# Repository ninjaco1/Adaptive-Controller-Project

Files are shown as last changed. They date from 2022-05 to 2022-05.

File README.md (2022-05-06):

# Adaptive-Controller-Project

ECE 44x Group 18
by Anthony Nguyen, Don Nguyen, Alyssa Estenson, Jordyn Marshall

The purpose of this project is to develop a controller which can act as a keyboard and a mouse when utilized with a computer. This controller is designed to help amputees or those incapable of controlling individual fingers be able to interact with a computer efficiently. This controller falls under the category of assistive technology, hoping to increase participation among the desired user group. The team has designed and prototyped an assistive controller that utilizes joysticks and large buttons to help those who lack fingers and appendages interact with a computer, when they would otherwise be unable to interact with a standard keyboard and handheld mouse.

This controller provides keyboard and mouse functionality. This controller has been designed to be intuitive for the expected disabled user group, and can be operated accurately and precisely. The device itself has been implemented to be integrable with the target user’s daily activities, meaning it is safe and is protected to allow only limited dust and particle ingress. The controller is powered and connected to the computer via a USB cable. The risks and impacts in several fields have been considered for this project in the final design and implementation of the system.

The team has designed the system by creating a block diagram and defining the interface connections between each block. The push buttons and joysticks are both blocks which allow for the user to interact with the system, while an input modification block is included so that these electronics can be properly utilized by the disabled user. All the inputs would then be processed by the Arduino, which is mounted to a PCB and connected to the rest of the system. The Arduino and any other electrical circuits would be contained within a smaller, safe enclosure within the system itself. Once the Arduino has interpreted the proper inputs, it would then tell the computer how to manipulate the cursor or what to type into a word processor based on the given inputs. This would be done with the keyboard serial and mouse serial blocks.

The team has since developed all blocks and integrated them together into a complete system. The system was shown to meet all of the project’s requirements and thus assert itself as a functional prototype. The team has since begun to close out the project, and have placed all information for future teams within the project closing section. The team has made several recommendations to improve future projects. As such, the project would be easily continued by future teams. These recommendations include implementing a testbench into the design, utilizing an I2C multiplexer for the joysticks, redesigning the enclosure for better fasteners, and include a demonstration for accuracy. The team also made global impact recommendations, which include finding a target user and lowering cost, as well as teamwork recommendations, which involve more synchronous meetings and task delegation.

## Getting things started
The system will start up and will display on the screen of what mouse sentivity the user wants. Each buttons will be a different DPI. Each Colored button will either be caps lock, shift, ctrl, or alt. To type a certain letter to the screen you move each controller in a certain different. If unsure where the letters are just hold the left joystick in a certain different for 1 second and the OLED display will show the possible letters that you want to type. If you want to use the mouse then just move only the right joystick. For a left click push down on the left joystick. For a right click push down on the right joystick.

## Images
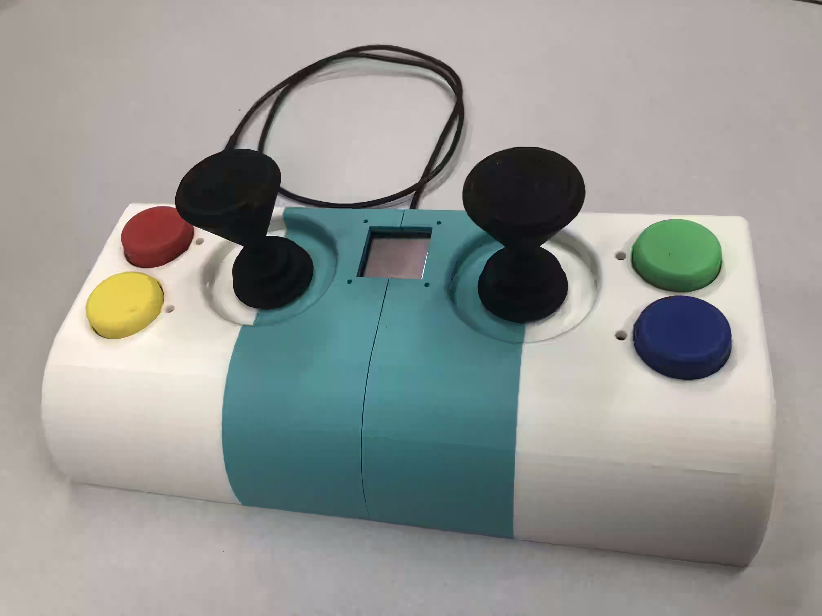
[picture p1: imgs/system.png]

<br>

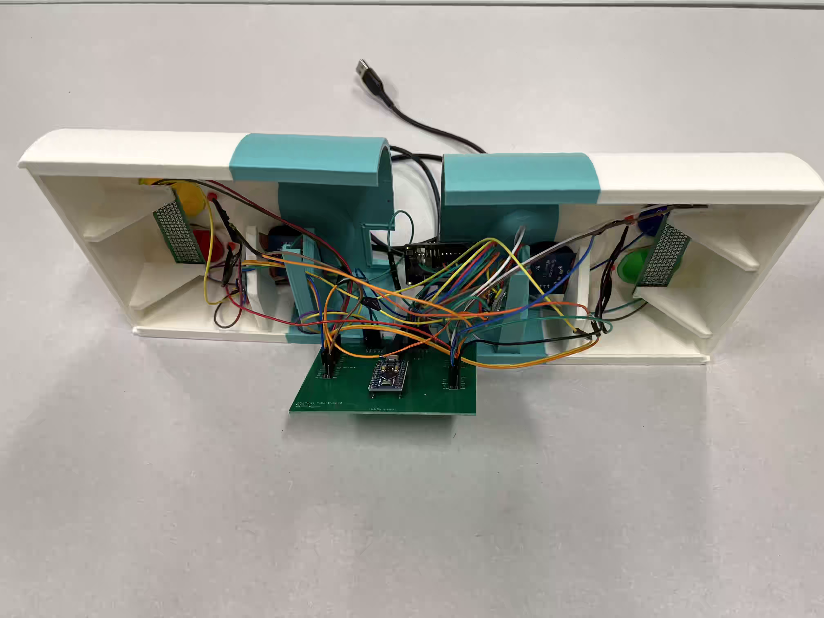
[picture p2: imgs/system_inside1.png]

<br>
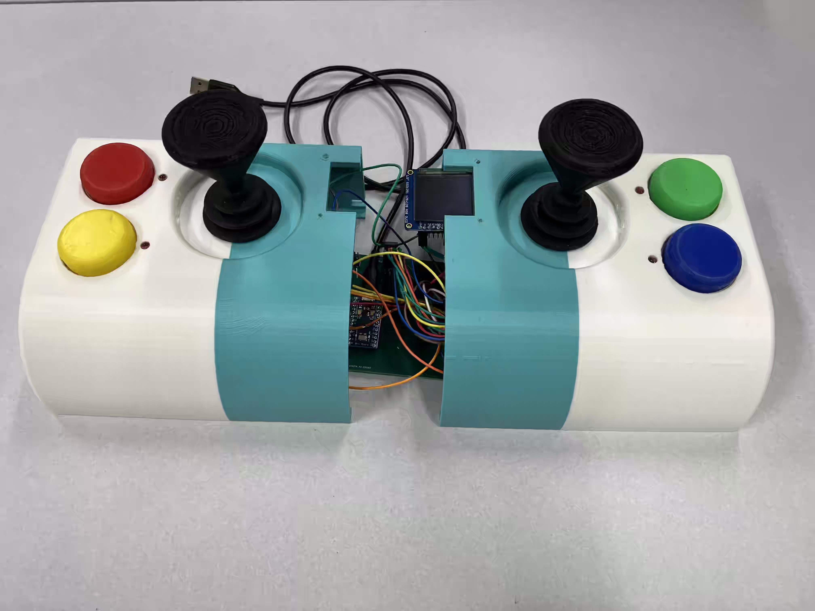
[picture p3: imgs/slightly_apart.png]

<br>

### Schematic of Connections


<br>

### Key mapping
<br>


## Links
[OSU Project Showcase](https://eecs.oregonstate.edu/project-showcase/projects/?id=dvNoBaSVptpGct7d)

[Project Poster](https://docs.google.com/presentation/d/1d2c_HKdiV-RKjupTTuDAdYsf7zG3z4g_/edit#slide=id.p1)

[BOM](https://docs.google.com/spreadsheets/d/1IXuZZz__ufx8j4xxZ3oTDNYRYh3Tj-c8Vc7RmFHtK2w/edit)

## Videos
[Keyboard Test video](https://drive.google.com/file/d/1GGf7FCQeNJFhevCrC33tzXw3Ll04iI_N/view)

[Mouse Test video](https://drive.google.com/file/d/1AdtP7RRNI2bLkL078hBE3vfOJWtM9V73/view)

[Drop Test video](https://drive.google.com/file/d/1iQLp1Ob5c2PGEaCn-phhR27NIFKvISCt/view)

[Sand Test Video](https://drive.google.com/file/d/1Eg6IK6emiSHccY-DuzBPpM0ZAq6DRVJi/view)

[Pasting Demo](https://drive.google.com/file/d/1w3BZ9_08Sq80-XbKwkToTu9jihAmKI4g/view)

[Testing Input Delay](https://drive.google.com/file/d/1sHcw7LDEvQJ_JNjOiiO1o_LZl5gAdzr4/view)

[Menu Display Testing](https://drive.google.com/file/d/1sHcw7LDEvQJ_JNjOiiO1o_LZl5gAdzr4/view)

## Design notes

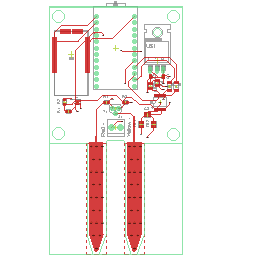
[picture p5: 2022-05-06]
F/_HC_Thesis_PCB.92a26f0b-b337-44cd-ba37-0ec76b757aee.png

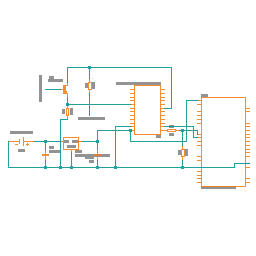
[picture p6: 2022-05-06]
F/_HC_Thesis_Schematic.0f503704-76ca-4dae-937e-57e30101aeb6.png

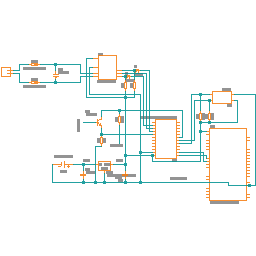
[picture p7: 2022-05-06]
F/_HC_Thesis_Schematic.15e804ea-fe3e-409c-88e3-dcfe19e1805c.png

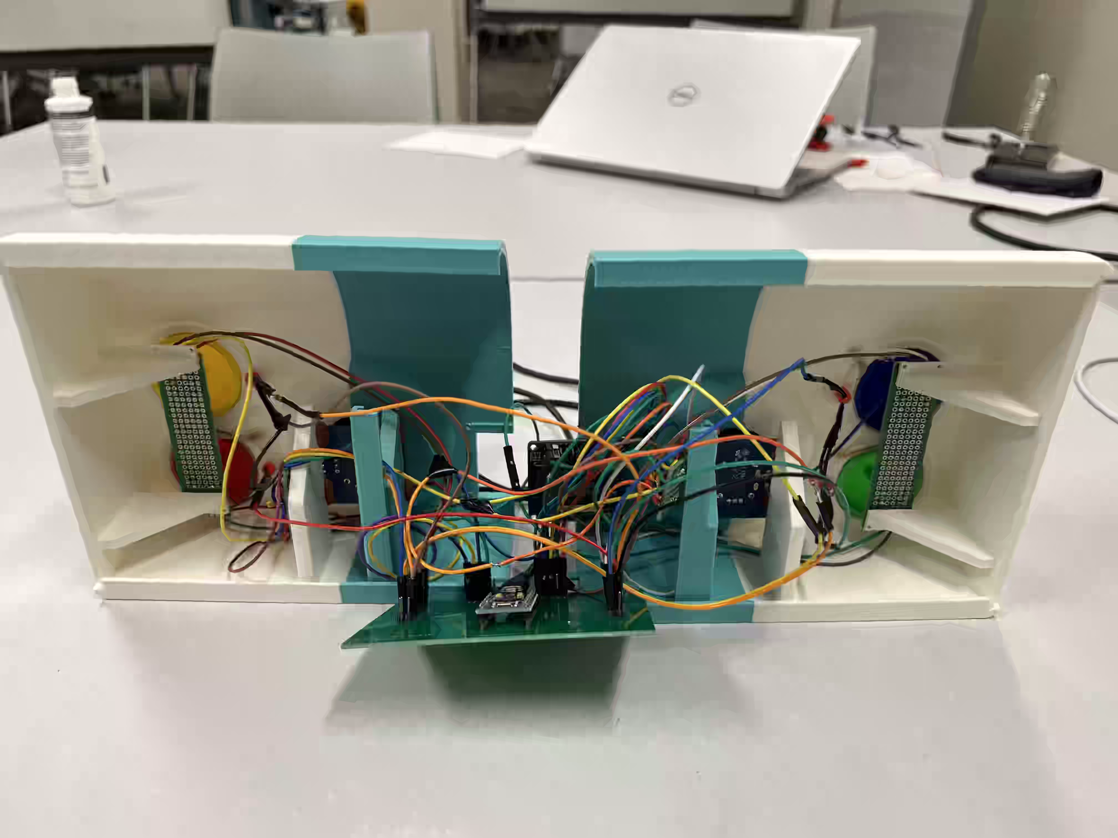
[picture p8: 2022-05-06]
imgs/system_inside2.png

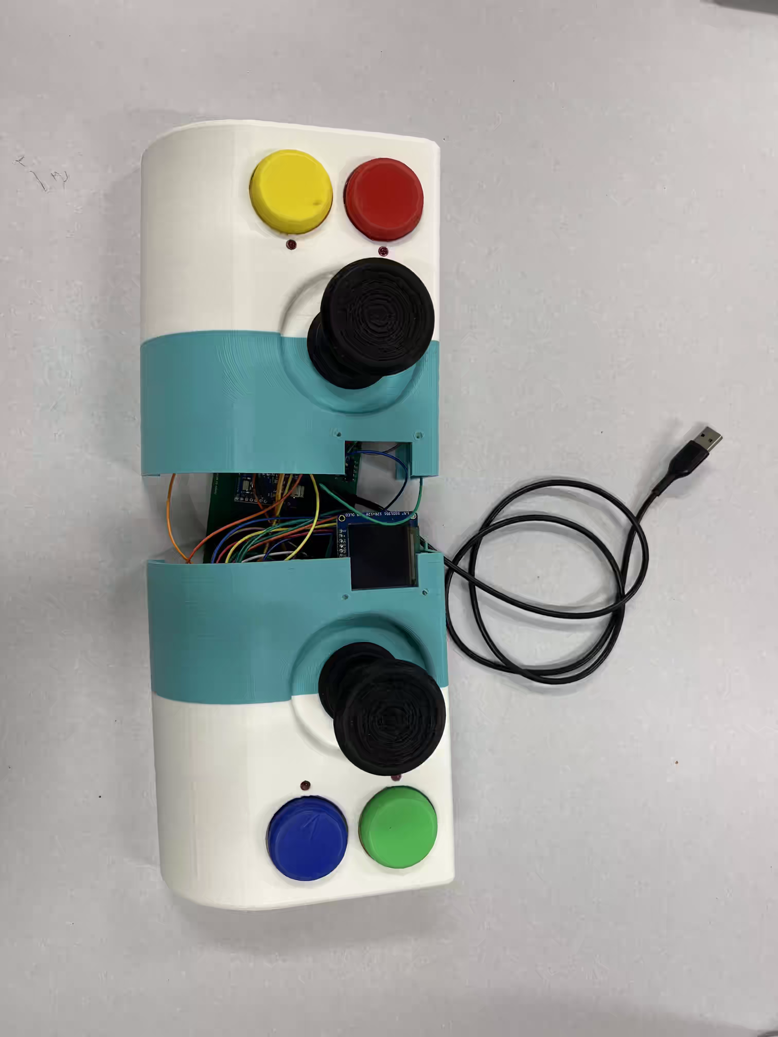
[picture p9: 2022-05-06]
imgs/vertical_slightly apart.png

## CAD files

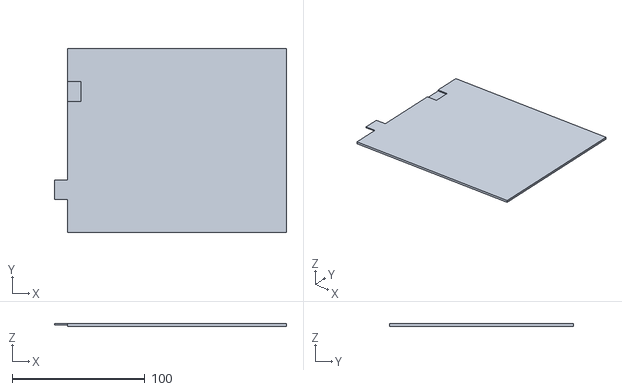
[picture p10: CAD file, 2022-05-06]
SlideLeft v1.stl
174.8 x 139.0 x 1.90

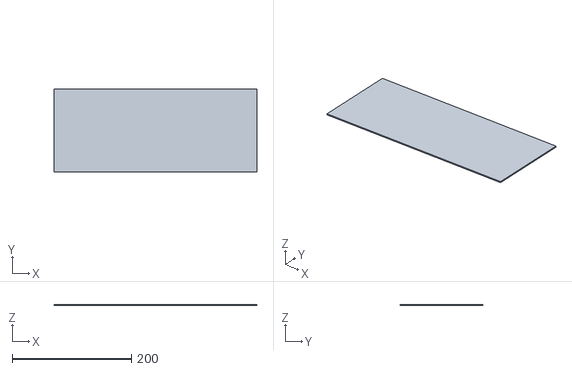
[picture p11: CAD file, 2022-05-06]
Bottom Slide v1.stl
340.0 x 139.0 x 1.90

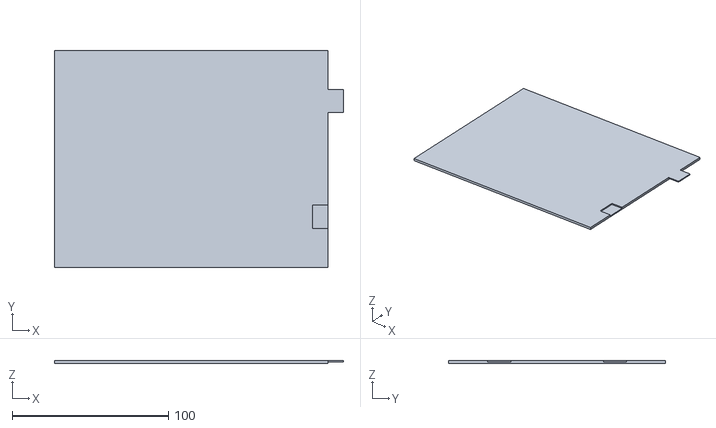
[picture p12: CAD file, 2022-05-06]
SlideRight v1.stl
184.8 x 139.0 x 1.90

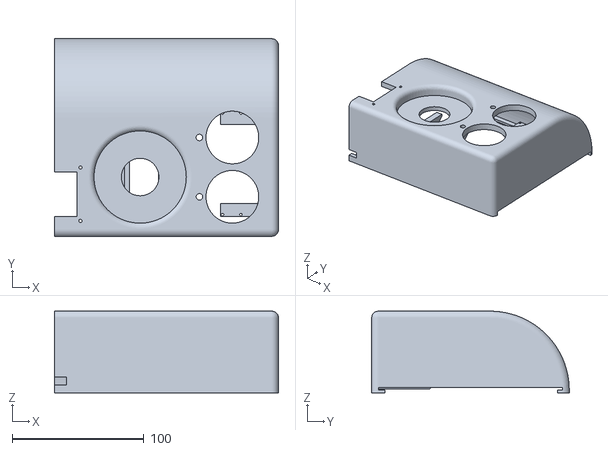
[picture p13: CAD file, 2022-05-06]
EnclosureLeft2 v1.stl
170.0 x 150.0 x 62.0

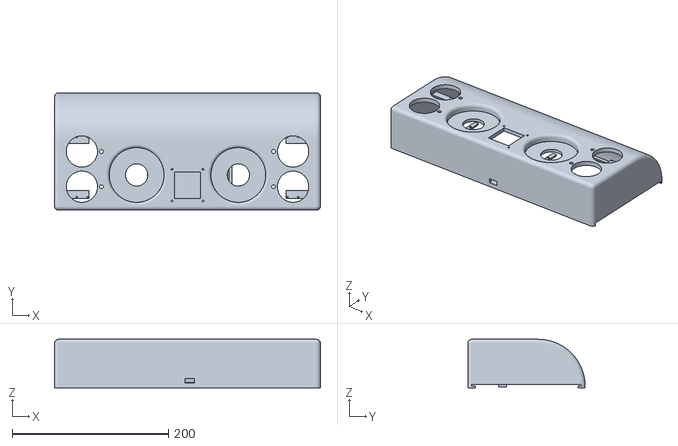
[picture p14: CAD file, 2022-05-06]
EnclosureEdit v5.stl
340.0 x 150.0 x 62.0

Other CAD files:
EnclosureRight v1.stl
EnclosureLeft2 v1.f3d
F/_Bottom Slide Drawing.b6d973e9-bf5a-411e-be44-02bcf0958e85.f2d
F/_Bottom Slide.52f3d79a-d360-466b-9179-13a9d49c522c.f3d
F/_Enclosure.4db8caeb-8215-4af4-88ae-bd1e58a5b23c.f3d
F/_EnclosureAdjust.fc7c3453-6717-43be-b58f-f00bd7b97b80.f3d
F/_EnclosureEdit Drawing.40aac79c-d90c-4c43-845f-02b9d95ee5f7.f2d
F/_EnclosureEdit.7de098fb-cdc2-4d50-8657-6a43fb820375.f3d
F/_EnclosureLeft.1aa5190f-d5e4-4d97-9be4-42d8a4ec4a47.f3d
F/_EnclosureLeft2.d6a65141-9274-40d2-aae8-db812ca37aa2.f3d
F/_EnclosureRight.7b88efe1-b6f1-4124-831b-9d16f9bb9ea6.f3d
F/_SlideLeft.8e61a6cf-9e6c-482f-872f-dd21ef670e3e.f3d
F/_SlideRight.b5ac7882-bd10-4640-b8c8-33c303472b0b.f3d

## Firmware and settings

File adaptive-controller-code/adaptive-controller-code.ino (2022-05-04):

// FEATURE SWITCH
#define MOUSEBLOCK TRUE;
#define JOYSTICKBUTTONBLOCK TRUE;
#define KEYBOARDBLOCK TRUE;
#define OLEDBLOCK TRUE;

#ifdef OLEDBLOCK
// You can use any (4 or) 5 pins
#define SCLK_PIN 15
#define MOSI_PIN 16
#define DC_PIN 8
#define CS_PIN 10
#define RST_PIN 7

// one of these 3 includes conflicts with the joysticks
#include <Adafruit_GFX.h>
#include <Adafruit_SSD1351.h>
#include <SPI.h>

// Color definitions
#define BLACK 0x0000
#define BLUE 0x001F
#define RED 0xF800
#define GREEN 0x07E0
#define CYAN 0x07FF
#define MAGENTA 0xF81F
#define YELLOW 0xFFE0
#define WHITE 0xFFFF
#define PURPLE 0x7810
#define ORANGE 0xFC00

// Screen dimensions
#define SCREEN_WIDTH 128
#define SCREEN_HEIGHT 128

Adafruit_SSD1351 tft = Adafruit_SSD1351(SCREEN_WIDTH, SCREEN_HEIGHT, CS_PIN, DC_PIN, MOSI_PIN, SCLK_PIN, RST_PIN);
bool setMouseSpeedFlag = false;
#endif

#ifdef JOYSTICKBUTTONBLOCK
#include "keyboard_serial_header.hpp"
#include <Wire.h>
#include "SparkFun_Qwiic_Joystick_Arduino_Library.h" //https://www.sparkfun.com/products/15168
//#include <TFT.h>
#define OFF 0
#define ON 1
#define RIGHT 2
#define LEFT 1
#endif

#ifdef MOUSEBLOCK
#include "Assistive_Mouse.h"
#endif

// declare joystick objects
#ifdef JOYSTICKBUTTONBLOCK
JOYSTICK Lstick;
JOYSTICK Rstick;
#endif

// declare keyboard object
#ifdef KEYBOARDBLOCK
Key k;
#endif

// declare mouse
#ifdef MOUSEBLOCK
Assistive_Mouse mouse;
#endif

#ifdef JOYSTICKBUTTONBLOCK
uint8_t Laddress = 0x20; // I2C address for left joystick (default)
uint8_t Raddress = 0x21; // I2C address for right joystick (reprogrammed)

// variables to hold joystick input
uint16_t LinX = 512; // ADC "coordinate" value from the ATtiny85
uint16_t LinY = 512; // ADC "coordinate" value from the ATtiny85
uint16_t RinX = 512; // ADC "coordinate" value from the ATtiny85
uint16_t RinY = 512; // ADC "coordinate" value from the ATtiny85
uint8_t Lkey = 00;   // input to convey to keyboard
uint8_t Rkey = 00;   // input to convey to keyboard

unsigned long timepass = 0; // variable to track time, start at 0

// button status variables, default OFF
uint8_t Lclick = OFF;
uint8_t Rclick = OFF;
uint8_t CAPS = OFF;  // CAPS state will be toggled...
uint8_t Shift = OFF; //... while other buttons work directly as switches
uint8_t Ctrl = OFF;
uint8_t Alt = OFF;
#endif

//******************************************************************************
//                            chk_buttons
// Checks the state of the button number passed to it. It shifts in ones till
// the button is pushed. Function returns a 1 only once per debounced button
// push so a debounce and toggle function can be implemented at the same time.
// Adapted to check all buttons from Ganssel's "Guide to Debouncing"
// Expects active low pushbuttons on PINA port.  Debounce time is determined by
// external loop delay times 12. Looks for rising edge on button so held actions
// have no unexpected effect.
//******************************************************************************
uint8_t chk_buttons(uint8_t pin)
{
    static uint16_t state = 0;                          // holds state of debounce reading
    state = (state << 1) | (digitalRead(pin)) | 0xE000; // mask on PINA button
    if (state == 0xEFFF)                                // compares to rising edge value (so holding doesn't stack)
        return 1;

    // if not true for 12 times, return false
    return 0;
}

//******************************************************************************
//                            chk_click
// Checks the state of the click passed to it. It shifts in ones till
// the button is pushed. Function returns a 1 only once per debounced button
// push so a debounce and toggle function can be implemented at the same time.
// Adapted to check all buttons from Ganssel's "Guide to Debouncing"
// Expects active low pushbuttons on PINA port.  Debounce time is determined by
// external loop delay times 12. Looks for rising edge on button so held actions
// have no unexpected effect.
//******************************************************************************
uint8_t chk_click(uint8_t which_click)
{
    static uint8_t state1 = 0; // holds state of right debounce reading
    static uint8_t state2 = 0; // holds state of left debounce
    if (which_click == RIGHT)
    {                                                          // right click
        state1 = (state1 << 1) | (!Rstick.getButton()) | 0xE0; // mask
        if (state1 == 0xEF)                                    // compares to rising edge value (so holding doesn't stack)
            return 1;

        // if not true for 4 times, return false
        return 0;
    }

    if (which_click == LEFT)
    {                                                          // left click
        state2 = (state2 << 1) | (!Lstick.getButton()) | 0xE0; // mask
        if (state2 == 0xEF)                                    // compares to rising edge value (so holding doesn't stack)
            return 1;

        // if not true for 4 times, return false
        return 0;
    }
}

//******************************************************************************
//                            mode_selector
//
//******************************************************************************
void mode_selector(uint8_t selector, uint8_t shift, uint8_t caps)
{
    switch (selector)
    {
    case 0:
        if(shift)
            visual_aid_display('K', 'O', ' ', 'M', ' ', ' ', 'L', 'N');
        else if(caps)
            visual_aid_display('K', 'O', ' ', 'M', ' ', ' ', 'L', 'N');
        else
            visual_aid_display('k', 'o', ' ', 'm', ' ', ' ', 'l', 'n');
        break;
    case 1:
        if(shift)
            visual_aid_display('P', 'T', '{', 'R', '}', ' ', 'Q', 'S');
        else if(caps)
            visual_aid_display('P', 'T', '[', 'R', ']', ' ', 'Q', 'S');
        else
            visual_aid_display('p', 't', '[', 'r', ']', ' ', 'q', 's');
        break;
    case 2:
        if(shift)
            visual_aid_display('U', 'Y', '\\', 'W', ' ', ' ', 'V', 'X');
        else if(caps)
            visual_aid_display('U', 'Y', '\\', 'W', ' ', ' ', 'V', 'X');
        else
            visual_aid_display('u', 'y', '\\', 'w', ' ', ' ', 'v', 'x');
        break;
    case 3:
        if(shift)
            visual_aid_display('<', 'Z', ' ', '"', ' ', ' ', '>', '?');
        else if(caps)
            visual_aid_display(',', 'Z', ' ', '\'', ' ', ' ', '.', '/');
        else
            visual_aid_display(',', 'z', ' ', '\'', ' ', ' ', '.', '/');
        break;
    case 4:
        if(!shift)
            visual_aid_display('6', '0', '-', '8', '=', ' ', '7', '9');
        else
            visual_aid_display('^', ')', '_', '*', '+', ' ', '&', '(');
        break;
    case 5:
        if(!shift)
            visual_aid_display('1', '5', ' ', '3', ' ', ' ', '2', '4');
        else
            visual_aid_display('!', '%', ' ', '#', ' ', ' ', '@', '$');
        break;
    case 6:
        if(shift)
            visual_aid_display('A', 'E', ' ', 'C', ' ', ' ', 'B', 'D');
        else if(caps)
            visual_aid_display('A', 'E', ' ', 'C', ' ', ' ', 'B', 'D');
        else
            visual_aid_display('a', 'e', ' ', 'c', ' ', ' ', 'b', 'd');
        break;
    case 7:
        if(shift)
            visual_aid_display('F', 'J', ' ', 'H', ' ', ' ', 'G', 'I');
        else if(caps)
            visual_aid_display('F', 'J', ' ', 'H', ' ', ' ', 'G', 'I');
        else
            visual_aid_display('f', 'j', ' ', 'h', ' ', ' ', 'g', 'i');
        break;
    default:
        tft.fillScreen(BLACK);
    }
}

//******************************************************************************
//                            visual_aid_display
//
//******************************************************************************
void visual_aid_display(char one, char two, char three, char four, char five, char six, char seven, char eight)
{
    //tft.fillScreen(BLACK);
    tft.fillCircle(tft.width() / 2, tft.height() / 2, tft.height() / 2 - 1, WHITE);
    tft.setTextSize(3);

    // Top
    tft.setCursor(tft.width() / 2 - 6, 5);
    tft.setTextColor(RED);
    tft.print(one);

    // Bottom
    tft.setCursor(tft.width() / 2 - 6, 105);
    tft.setTextColor(YELLOW);
    tft.print(two);

    // Left
    tft.setCursor(5, tft.height() / 2 - 10);
    tft.setTextColor(PURPLE);
    tft.print(three);

    // Right
    tft.setCursor(108, tft.height() / 2 - 10);
    tft.setTextColor(ORANGE);
    tft.print(four);

    // Top Left
    tft.setCursor(25, 20);
    tft.setTextColor(GREEN);
    tft.print(five);

    // Bottom Left
    tft.setCursor(25, 90);
    tft.setTextColor(BLUE);
    tft.print(six);

    // Top Right
    tft.setCursor(90, 20);
    tft.setTextColor(MAGENTA);
    tft.print(seven);

    // Bottom Right
    tft.setCursor(90, 90);
    tft.setTextColor(CYAN);
    tft.print(eight);
}

void setup()
{
    // put your setup code here, to run once:
    Serial.begin(9600);

#ifdef OLEDBLOCK
    tft.begin();
    tft.setRotation(2);
    tft.fillScreen(BLACK);
#endif

#ifdef JOYSTICKBUTTONBLOCK
    if (Lstick.begin(Wire, Laddress) == false)
    {
        Serial.println("Left Joystick does not appear to be connected. Please check wiring. Freezing...");
        while (1)
            ;
    }

    if (Rstick.begin(Wire, Raddress) == false)
    {
        Serial.println("Right Joystick does not appear to be connected. Please check wiring. Freezing...");
        while (1)
            ;
    }

    mouse.start();

    // pinMode for buttons
    pinMode(4, INPUT); // change values later
    pinMode(5, INPUT); // change values later
    pinMode(6, INPUT); // change values later
    pinMode(9, INPUT); // change values later
#endif

    //LED Diodes
    pinMode(18, OUTPUT);
    pinMode(19, OUTPUT);
    pinMode(20, OUTPUT);
    pinMode(21, OUTPUT);
    
    // flags for the menu
    // bool setMouseSpeedFlag = false;

    tft.setCursor(0, 0);
    tft.setTextColor(WHITE);
    tft.setTextSize(1);
    tft.print("Please Select Mouse  Sensitivity:");

    tft.setCursor(0, 20);
    tft.setTextColor(WHITE);
    tft.print("RED: Low");

    tft.setCursor(0, 30);
    tft.setTextColor(WHITE);
    tft.print("YELLOW: Normal");

    tft.setCursor(0, 40);
    tft.setTextColor(WHITE);
    tft.print("BLUE: Fast");
    // reading dummny
    chk_buttons(4);
    chk_buttons(5);
    chk_buttons(6);
    chk_buttons(9);
        chk_buttons(4);
    chk_buttons(5);
    chk_buttons(6);
    chk_buttons(9);
        chk_buttons(4);
    chk_buttons(5);
    chk_buttons(6);
    chk_buttons(9);
        chk_buttons(4);
    chk_buttons(5);
    chk_buttons(6);
    chk_buttons(9);
    _delay_ms(1000);

    while (1)
    {
        // leave the menu when done

        // let buttons choose sentivity
        if (chk_buttons(4))
        {
            mouse.set_sensitivity(0.5);
            break;
        }

        if (chk_buttons(5))
        {
            mouse.set_sensitivity(1);
            break;
        }
        if (chk_buttons(6))
        {
            mouse.set_sensitivity(2);
            break;
        }
    }

    tft.fillScreen(BLACK);
    tft.fillCircle(tft.width() / 2, tft.height() / 2, tft.height() / 2 - 1, WHITE);

}

void loop()
{

#ifdef JOYSTICKBUTTONBLOCK
    // gather coord data from joystick (0-1023)
    LinX = Lstick.getHorizontal();
    LinY = Lstick.getVertical();
    Lclick = chk_click(LEFT); // send 1 for left click, 2 for right (reflect mouse click)

    RinX = Rstick.getHorizontal();
    RinY = Rstick.getVertical();
    Rclick = chk_click(RIGHT); // send RIGHT for right click, LEFT for left click

    // Parse joystick data for keyboard

    // LEFT STICK: if X is to the left
    if (LinX < 470)
    { // about 60 (~20%) away from center to constitute change
        // three cases for Y
        if (LinY < 470)
            Lkey = 15;
        else if (LinY > 575)
            Lkey = 17;
        else
            Lkey = 16;
    }
    // if X is to the right
    else if (LinX > 575)
    {
        // three cases for Y
        if (LinY < 470)
            Lkey = 13;
        else if (LinY > 575)
            Lkey = 11;
        else
            Lkey = 12;
    }
    // if X is in the middle
    else
    {
        // three cases for Y
        if (LinY < 470)
            Lkey = 14;
        else if (LinY > 575)
            Lkey = 10;
        else
            Lkey = 00;
    }

    // RIGHT STICK: if X is to the left
    if (RinX < 470)
    { // about 60 (~20%) away from center to constitute change
        // three cases for Y
        if (RinY < 470)
            Rkey = 25;
        else if (RinY > 575)
            Rkey = 27;
        else
            Rkey = 26;
    }

    // if X is to the right
    else if (RinX > 575)
    {
        // three cases for Y
        if (RinY < 470)
            Rkey = 23;
        else if (RinY > 575)
            Rkey = 21;
        else
            Rkey = 22;
    }

    // if X is in the middle
    else
    {
        // three cases for Y
        if (RinY < 470)
            Rkey = 24;
        else if (RinY > 575)
            Rkey = 20;
        else
            Rkey = 00;
    }

    // Check pushbuttons, account for debouncing
    if (chk_buttons(4))
    {
        CAPS = CAPS ^ 1;
        k.toggle_caps_lock();
        //tft.fillScreen(RED);
        digitalWrite(18,CAPS); // A0
    }
    else if (chk_buttons(5))
    {
        Shift = 1;
        k.toggle_shift();
        //tft.fillScreen(YELLOW);
        digitalWrite(19,Shift); // A1
    }
    else if (chk_buttons(6))
    {
        Ctrl = 1;
        k.toggle_ctrl();
        //tft.fillScreen(BLUE);
        digitalWrite(20,Ctrl); // A2
    }
    else if (chk_buttons(9))
    {
        Alt = 1;
        k.toggle_alt();
        //tft.fillScreen(GREEN);
        digitalWrite(21,Alt); // A3
    }
#endif

    // Print button, joystick, and keyboard output maximum of 100ms (10Hz). After, reset button status (besides CAPS)
    if (millis() >= (timepass + 100))
    {
        static uint8_t leftJoystickCounter = 0;
        static bool clearVisualAid = 0;

#ifdef JOYSTICKBUTTONBLOCK &&MOUSEBLOCK
        if (Lkey == 0)
        {

            //******************** Mouse Serial Code *****************
            if (Rclick)
            {
                mouse.click(RIGHT);
            }
            if (Lclick)
            {
                mouse.click(LEFT);
            }
            mouse.move(RinX, RinY, 0);
            Rclick = 0;
            //******************** Mouse Serial End ******************

            leftJoystickCounter = 0;

            if(clearVisualAid){
                tft.fillCircle(tft.width() / 2, tft.height() / 2, tft.height() / 2 - 1, WHITE);
                clearVisualAid = 0;
            }

        }
#endif

#ifdef JOYSTICKBUTTONBLOCK &&KEYBOARDBLOCK
        if (Lkey != 0)
        {
            static uint8_t prevRkeyState = 0;
            static bool resetJoystickState = true;

            timepass = millis(); // set timer to next increment
            leftJoystickCounter++;

            if (leftJoystickCounter == 10)
            {
                mode_selector(Lkey % 10, k.get_shift(), k.get_caps());
                clearVisualAid = 1;
            }

            if (prevRkeyState != Rkey && resetJoystickState == true)
            {
                k.keyboard_serial(Lkey, Rkey);
                Shift = 0;
                Ctrl = 0;
                Alt = 0;
                digitalWrite(19,Shift);
                digitalWrite(20,Ctrl);
                digitalWrite(21,Alt);
                k.reset_keys();
            }
  
            if (Rkey == 0)
                resetJoystickState = true;
            else
                resetJoystickState = false;
            prevRkeyState = Rkey;

            // Reset all non-CAPS buttons
            Lclick = 0;
            Rclick = 0;
            Shift = 0;
            Ctrl = 0;
            Alt = 0;

        }
#endif
    }
}

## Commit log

2022-04-20 the usb has problems
    [adaptive-controller-code.ino]
2022-05-06 Add enclosure files
    [_Bottom Slide Drawing.b6d973e9-bf5a-411e-be44-02bcf0958e85.f2d, _Bottom Slide.52f3d79a-d360-466b-9179-13a9d49c522c.f3d, _Enclosure.4db8caeb-8215-4af4-88ae-bd1e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]
2022-05-06 Add stl files
    [Bottom Slide v1.stl, EnclosureEdit v5.stl, EnclosureLeft2 v1.f3d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]
